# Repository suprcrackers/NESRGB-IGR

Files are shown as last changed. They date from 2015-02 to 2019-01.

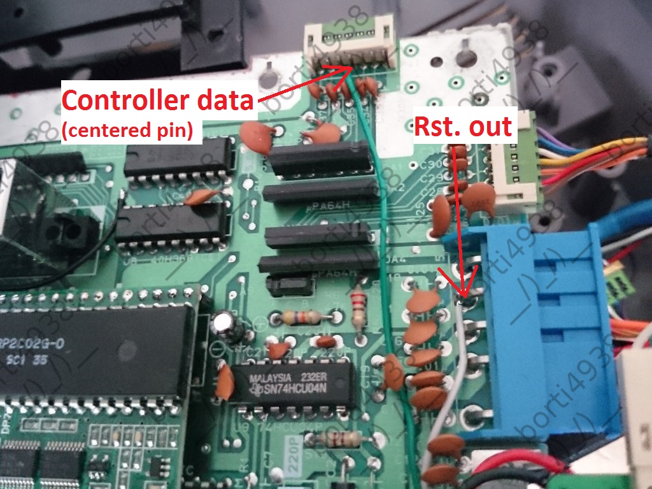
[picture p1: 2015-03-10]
Normal-Version/Installation/Frontloader_ResetOut_Data.jpg

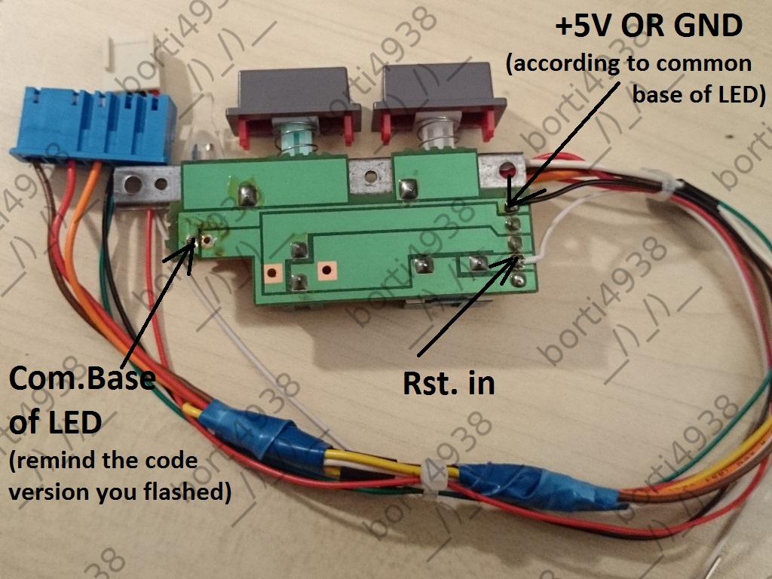
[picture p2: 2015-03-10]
Normal-Version/Installation/Frontloader_Frontpanel_mod.jpg

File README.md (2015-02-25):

# NESRGB-IGR
here you find PCBs and Codes for the NESRGB-IGR :)

If you successfully add the NESRGB-IGR you have the following functionalities available:  

Controller: Start+Select+ ...  
    - ... A+B pressed for <2s: short reset  
    - ... A+B pressed for >2s: long reset (going back to main menu if a power pak is used or in EDN8 reset to game is enabled)  
    - ... D-Pad right: Forward switching through the palette and RGB off (RGB off only available if set by jumper)  
    - ... D-Pad left: Backward switching through palette  
Reset:  
    - short push <~750ms: reset  
    - second punsh while PIC resets the NES/FC: reset as long long as button is held  
    - keeping pressed: forward switching through the palette and RGB off with delay of ~750ms for each palette   

Please note that one is not allowed to connect the PIC directly to the NESRGB.  
If you do so, the CPLD on the NESRGB will be destroyed because the PIC running with NESRGB-IGR-code is designed to run with +5V.  
I recommend to use a 74LVX125 running with 3.3V in between - this IC allows inputs up to +5V.

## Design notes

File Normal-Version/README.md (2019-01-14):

Grab the firmware for the PIC16F684 [here](https://github.com/borti4938/Switchless-Mods/tree/master/NES/IGR_for_NESRGB/)

-  current version: use the 'normal version' and flash the nesrgb_igr_684_var_led.hex
- oldest PCB version (with three 10k resistors next to the 74*125): use the 'risky version' and flash nesrgb_igr_684_risky_var_led.hex

The assembler file include some installation notes which can be used if you want to install the mod into a non-frontloader NES.

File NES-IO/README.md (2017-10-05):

NES-I/O
========

an idea by Arcade-TV from circuit-board.de :) Thank you very much!!!

The board replaces the silver box in NES frontloader. On this PCB the following components are included:

- AC input jack
- AC to DC conversion
- MultiAV (SNES and GC(*) are supported) 
- PIC16F684 microcontroller to control the NESRGB color palette and reset the console using your controller :D

All components you need are stated on the silkscreen. An complete overview as well as an English installation guide is coming soon ;)

Grab the firmware for the PIC16F684 here: https://github.com/borti4938/Switchless-Mods/tree/master/NES/IGR_for_NESRGB/
- current version: use the 'normal version' and flash the nesrgb_igr_684_var_led.hex
- oldest PCB version (with three 10k resistors next to the 74*125): use the 'risky version' and flash nesrgb_igr_684_risky_var_led.hex

(*) 3d-printed Helder/Buffalowing connector on assemblergames (http://assemblergames.com/l/threads/f-s-nes-top-loader-snes-style-multi-a-v-socket.50494/) also fits  
    thanks for figuring out, splits (shmups forum)

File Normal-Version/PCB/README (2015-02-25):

Components:

IC1: PIC16F684 SOIC-14 with NESRGB-IGR code. Please choose whether you want to use a dual LED with a common anode or cathode in advance!
IC2: 74LVX125 SOIC-14

C1, C2: 100nF 0805
R1, R2: 220Ohm 0805

Jumper:

J1: 10kOhm 0805 -> set the reset type of your console there.
J2: Short the jumper you want to... '3' means that the PIC cycles only through the RGB modes; '4' als cycles through RGB off

PCB-order:

Please choose your preferred service.
You may order that PCB at OSHPark -> https://oshpark.com/shared_projects/C9jdssMN

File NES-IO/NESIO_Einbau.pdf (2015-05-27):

# Workflow

### - Jumper festlegen - Alle Litzen und das Video Kabel werden an der Helferplatine

vorbereitet.

### - Das 6-adrige beigelegt Kabel ist für Audio/Video-Leitung, damit auf dem Weg von der NESRGB-PCB zur Helferplatine keine Störungen eingefangen werden! - Die Schirmung des 6-adrigen Kabels geht an Masse - Der 4-Pin-Header mit Buchse und Crimp-Kontakte ist optional!

Litzen können auch direkt auf die Pads gelötet werden.

### (Ich habe die Litzen in die Crimp-Kontakte gelötet und mit ner einfachen Zange zusammengedrückt )

- Der große 5-Pin-Header wird erst auf die Helferplatine gelötet,

### später mit dem NES verbunden. Leider gibt es dort keine Masse. Die

muss leider per Hand gelegt werden.

## Alles im Detail später – auf geht‘s ^^

# Jumper setzen

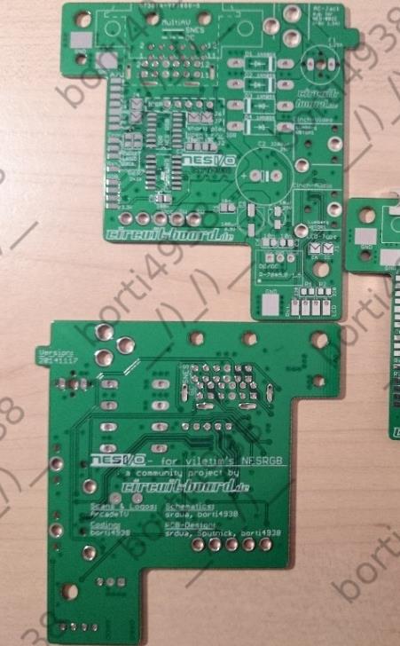
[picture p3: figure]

Es gibt insgesamt 7 Jumper auf der Platine verteilt
- J1: LED-Type: einen der beiden Pads kurzschließen.
CA = gem. Pluspol an LED
CC = gem. Minuspol an LED
- J2: Ist einfach nur n 10k Widerstand (vorgelötet)
- J3: #Modes entfällt in der aktuellen Version – drei Modi ist Fix!!!
- J4: MAV-Pin9. Entscheidet euch, womit gesynct werden soll bei RGB
oben: mit dem Composite Sync bzw. Luma unten: mit Composite Video
- J5: entfällt/nicht vorhanden.
- J6/J7: Die müssen nur aufgemacht werden, wenn man den NESRGB-IGR neu flashen möchte. Im Betrieb gehören die ZU!!!

# Litzen vorbereiten Part 1

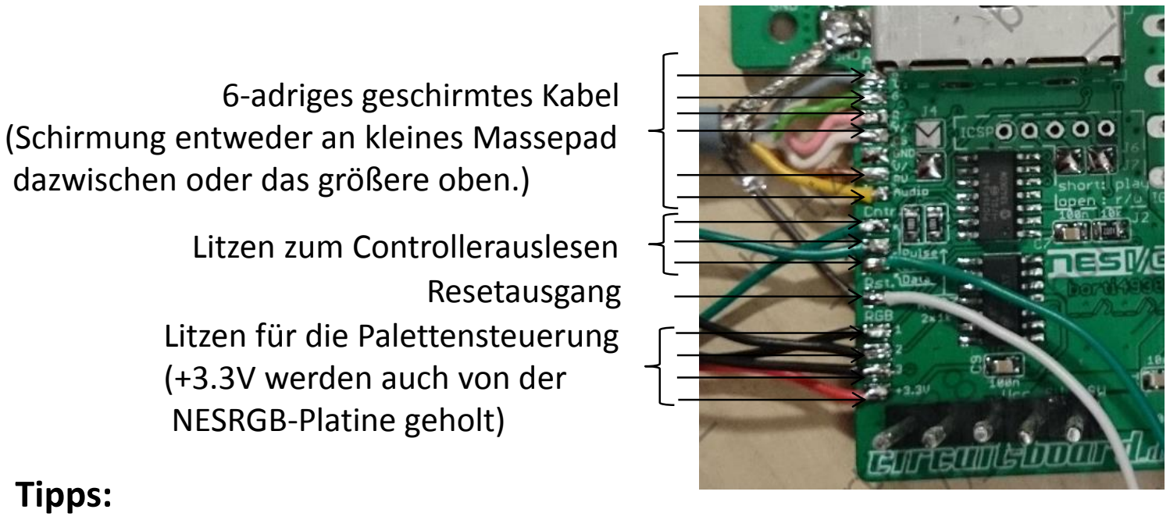
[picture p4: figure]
6-adriges geschirmtes Kabel (Schirmung entweder an kleines Massepad dazwischen oder das größere oben.); Litzen für die Palettensteuerung (+3.3V werden auch von der NESRGB-Platine geholt); Litzen zum Controllerauslesen Resetausgang; Tipps:

- Litze für Resetausgang und Data (Controller) nach rechts wegführen
- Massepads sind für Massekabel und werden später gelötet
(muss nicht vorbereitet werden)

# Litzen vorbereiten Part 2

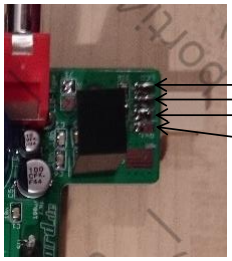
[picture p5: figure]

Tipps:
- GND-Pad wird später genutzt
- Reseteingang und LED-Steuerung kommen vom Frontpanel,
wo LED, Powerknopf und Resetknopf drauf sind. Deswegen empfiehlt sich hier n Pinheader mit Buchse, es sind aber auch einfache Litzen möglich (hier längere Litzen einplanen)
- Wenn Pinheader: BITTE von unten anbringen

LED-Steuerung (von oben nach unten: R, gem. Pol, G) Reseteingang

# NES-Mainboard vorbereiten

- Vor der Vereinigung von Helferplatine und NES-Mainboard,

## noch n Masseleitung anbringen - Masseleitung muss n gute Dicke haben (man kann auch mehrere verlegen; ich habe zwei verlegt)

Ich habe die ‚alten‘ Masselöcher der Box dafür verwendet,

## von unten n Litze anzubringen - Für den Elko muss n kleine Ecke vom Mainboard abgeknipst

oder abgefeilt werden.

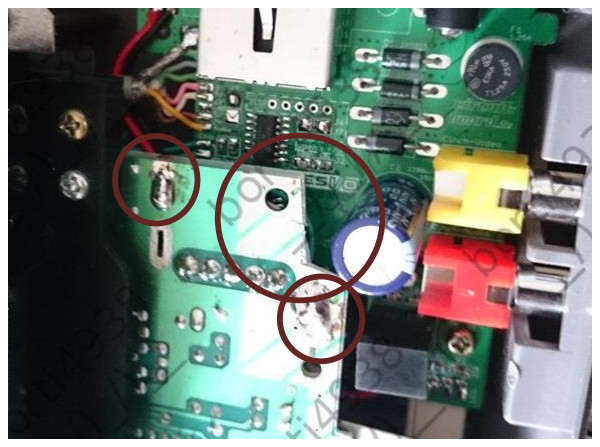
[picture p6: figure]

# Mit NES „vereinen“

### Damit alles gut sitzt, empfiehlt es sich, wie folgt vorzugehen: - 5-Pin-Header auf die Helferplatine löten! - Helferplatine im Gehäuse festschrauben - Untere Schirmung reinlegen, dabei muss ein kleines Ende unter die

Helferplatine geschoben werden.

(Litzen vorsichtig so hinlegen, dass keine im Weg ist) - Mainboard auflegen und auch provisorisch festschrauben (hier nochmal auf die losen Litzen achten) - Schauen, dass alles gut sitzt - 5-Pin-Header anlöten - Masseleitung auf die großen Pads der Helferplatine anlöten - Alles wieder ausschrauben und rausnehmen

### Nun geht’s auf die Zielgeraden

# Audio/Video verlegen

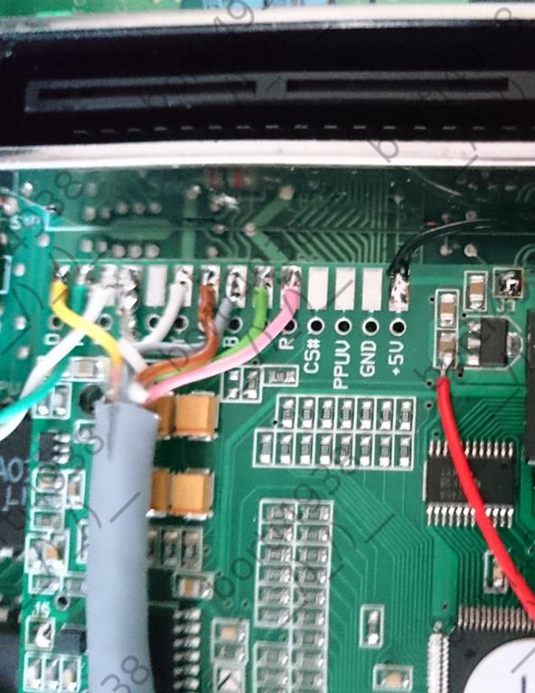
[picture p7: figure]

- Für das Audio/Video-Kabel eine angenehme Länge wählen
- ACHTUNG: Mit der Masseschirmung keinen Kurzschluss auf dem NESRGB-Board verursachen -> ggf. Abisolieren
- Achtet auf die Farben, die ihr an der Helferplatine gewählt habt!
- Audio ist „O“
- Video: entscheidet ob PPUV oder V
- CS: entscheidet, ob /CS oder Y. Dieses Signal liegt später am MultiAV Pin 7 an (für die ‚Luma‘-Syncer)

# Litzen verlegen – Part 1

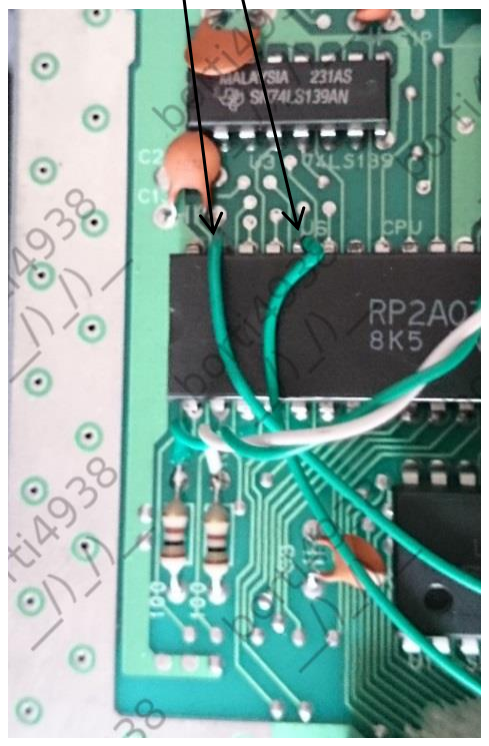
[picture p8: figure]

Controller Latch (U6 CPU Pin39)
Controller Pulse (U6 CPU Pin36)

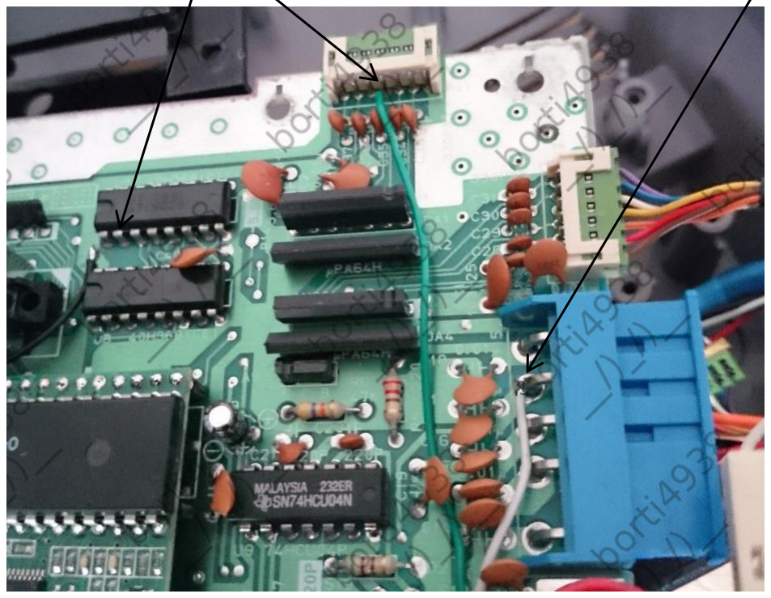
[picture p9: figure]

Controller Data (U7 Pin2) oder am Joypad-Anschluss Pin 4

Resetausgang
(zweiter Pin von unten,
alternativ CIC Pin7)

# Litzen verlegen – Part 2

Palettenswitch
(auf 1, 2 und 3 achten)

+3.3V
(am Kerko mit anlöten)

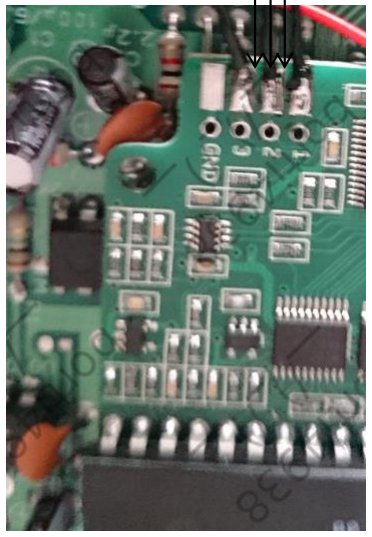
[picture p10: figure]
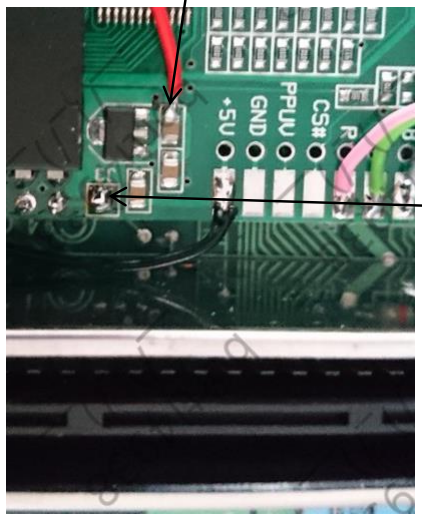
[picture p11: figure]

Hinweis:
Dieser Jumper kann zu und der zum NESRGB-Board beiliegende DC/DC weggelegt werden ;)

# Litzen verlegen – Part 3

Reseteingang
(zweiter von oben)
LED-C
(gemeinsamer Pol)
- Original LED entfernen und eine RG- oder RGB-LED einsetzen
- Gemeinsamer Pol durch die hier rechte Durchkontaktierung

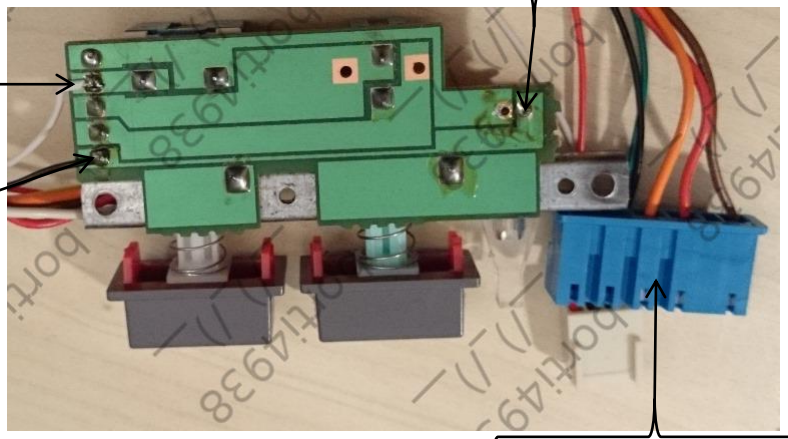
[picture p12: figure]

An diesem Stecker müssen das gelbe und das weiße Kabel (Pin 4 und 5) entfernt werden
(abknipsen oder den Stift rausdrücken)

# FERTIG

# Viel Spaß !!!

# PS: beim Zusammenbauen darauf achten, dass keine Litze gequetscht wird. Aber eigentlich sollte alles passen

# Fragen und Hinweise bitte an borti4938@gmx.de

# Funktionsweise NESRGB-IGR

- Controller: Start+Select+ ...
- ... A+B gedrückt unter 2s: Kurzer Reset
- ... A+B gedrückt für über 2s: Langer Reset
(zurück ins Hauptmenü beim Power Pak)
- ... D-Pad rechts:
Vorwärts durch die Paletten und durch RGB off schalten
(Delay je 750ms; RGB off nur bei entsprechend gesetztem Jumper)
- ... D-Pad left: Rückwärts durch die Paletten schalten
- Resetknopf:
- kurzes Drücken unter 750ms: Reset
- Beim Reset erneut drücken und gedrückt halten:
Reset wird solange durchgeführt, wie der Knopf gehalten wird
- Langes Drücken mind. Über 750ms:
Vorwärts durch die Paletten und durch RGB off schalten
(Delay je 750ms; RGB off nur bei entsprechend gesetztem Jumper)

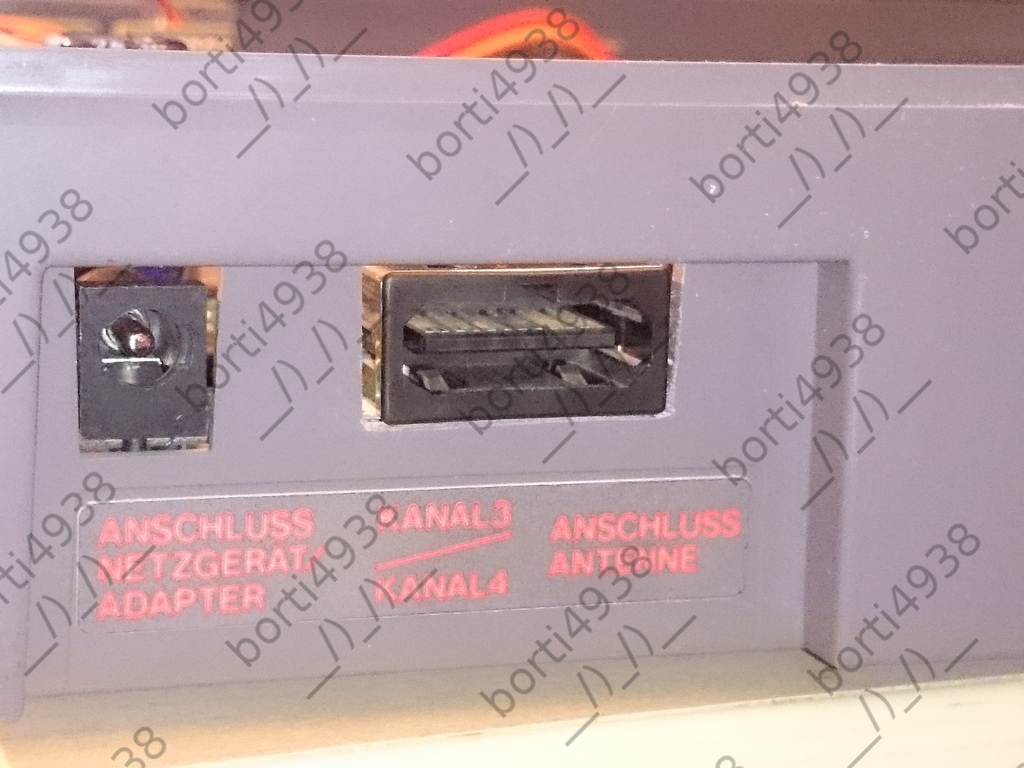
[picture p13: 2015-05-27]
NES-IO/pictures/GC-Buchse.jpg

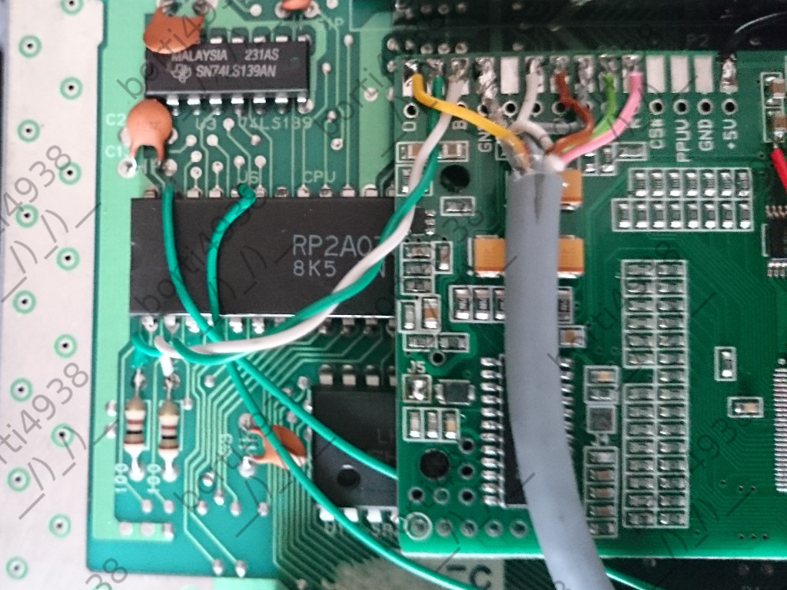
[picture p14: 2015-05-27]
NES-IO/pictures/Clk_Pulse.jpg

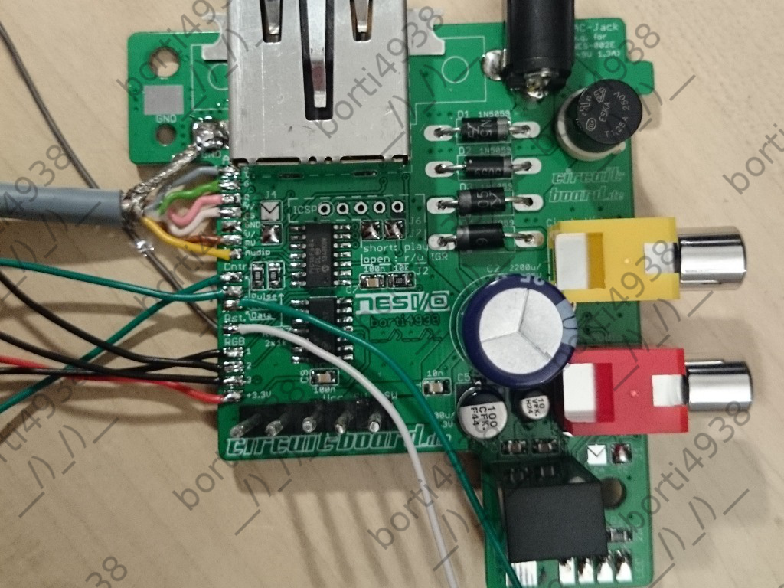
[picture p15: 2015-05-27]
NES-IO/pictures/Litzenvorbereitung.jpg

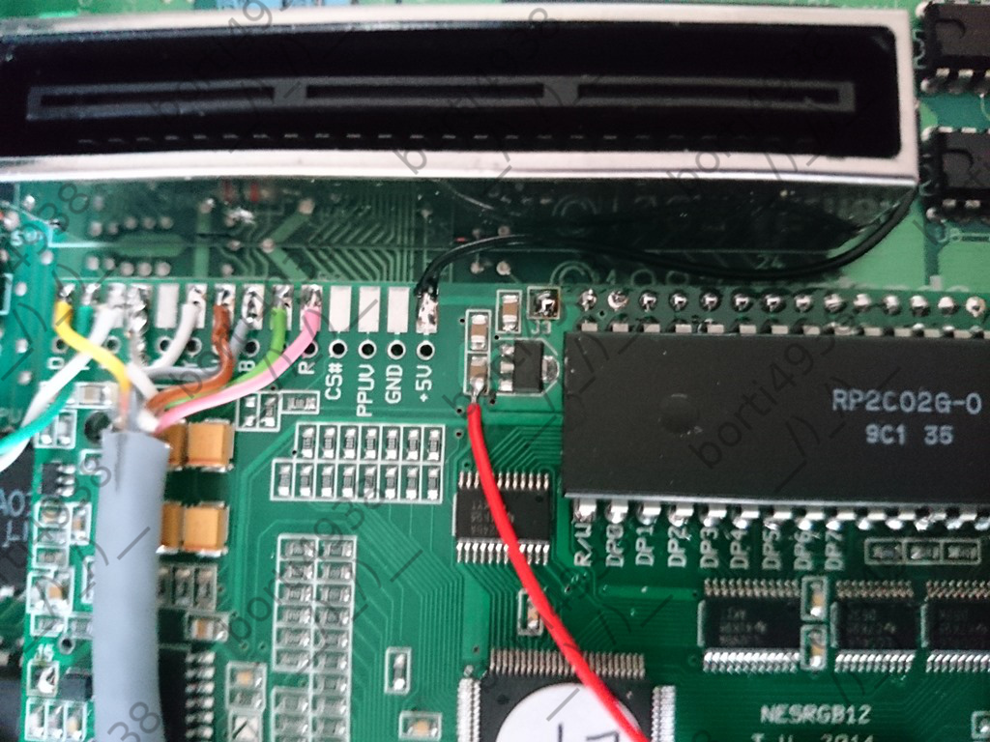
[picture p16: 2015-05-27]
NES-IO/pictures/NESRGB.jpg

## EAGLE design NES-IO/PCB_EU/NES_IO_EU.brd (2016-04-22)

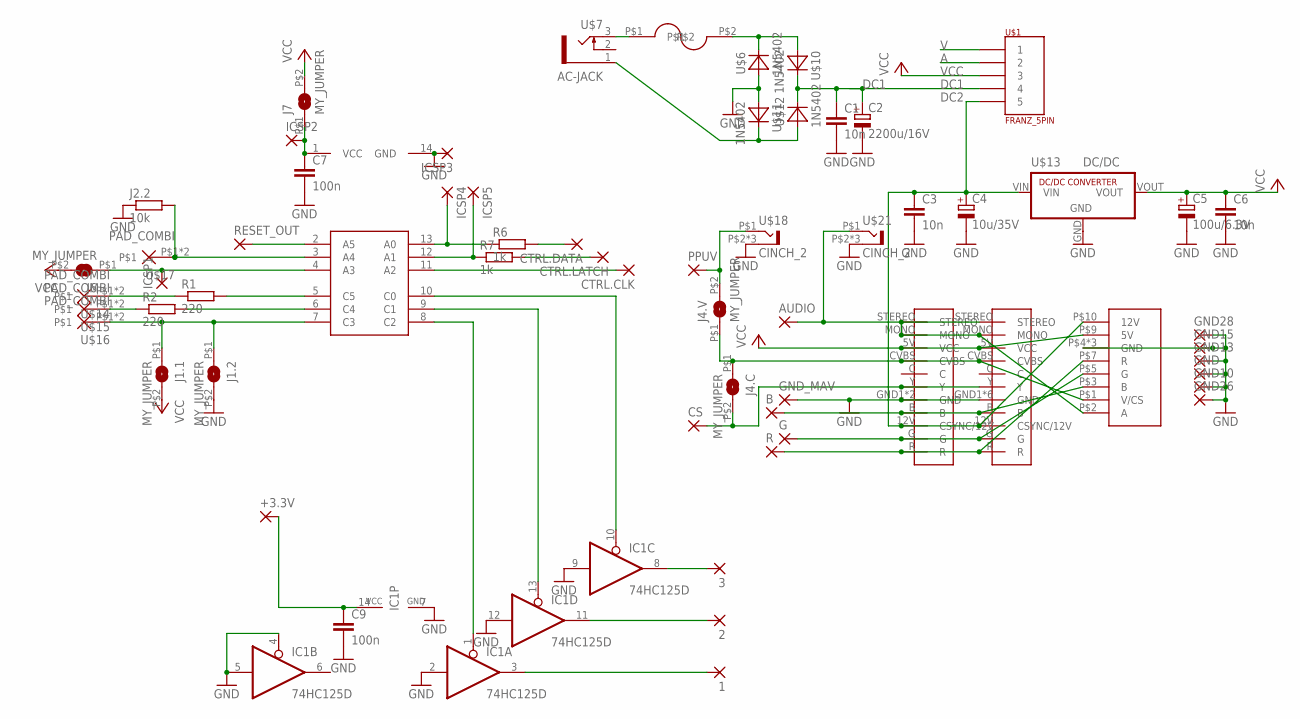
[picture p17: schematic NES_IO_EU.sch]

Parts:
1, 2, 3: SMD2; SMD1,27-2,54
+3.3V: SMD2; SMD1,27-2,54
AUDIO: SMD2; SMD1,27-2,54
B: SMD2; SMD1,27-2,54
C1, C3, C6: 10n; Z0805
C2: 2200u/16V; E5-13
C4: 10u/35V; PANASONIC_B
C5: 100u/6.3V; PANASONIC_D
C7, C9: 100n; Z0805
CS: SMD2; SMD1,27-2,54
CTRL.CLK, CTRL.DATA, CTRL.LATCH: SMD2; SMD1,27-2,54
G: SMD2; SMD1,27-2,54
GND, GND10, GND13, GND15, GND26, GND28: SMD5; SMD2,54-5,08
GND_MAV: SMD2; SMD1,27-2,54
IC1: 74HC125D; SO14
ICSP1, ICSP2, ICSP3, ICSP4, ICSP5: 1,6/0,8
J1.1, J1.2, J4.C, J4.V, J6, J7: MY_JUMPER; MYJUMP
J2.2: 10k; Z0805
PPUV: SMD2; SMD1,27-2,54
R: SMD2; SMD1,27-2,54
R1, R2: 220; Z0805
R6, R7: 1k; Z0805
RESET_OUT: SMD2; SMD1,27-2,54
U$1: FRANZ_5PIN; 5X2.22RM4
U$2: FUSEHOLDER
U$5: PIC16F630_SIMPLE; PIC16F630
U$6, U$10, U$11, U$12: 1N5402; DO201
U$7: AC-JACK
U$8: NESFR_JACK2
U$13: DC/DC; RECOM
U$14, U$15, U$16, U$17: PAD_COMBI
U$18, U$21: CINCH_2
U$19: GC-MULTIAV
U$20: SNES-MULTIAV2

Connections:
A: U$1.P$2 (2)
AC1A: U$2.P$1, U$7.3
AC1B: U$2.P$2, U$6.C, U$10.A
AC2: U$7.1 (5), U$11.C, U$12.A
DC1: C1.1, C2.+, U$1.P$4 (4), U$10.C, U$12.C
DC2: C3.1, C4.+, U$1.P$5 (5), U$8.P$10 (12V), U$13.VIN, U$19.12V (CSYNC/12V), U$20.12V (CSYNC/12V)
GND: C1.2, C2.-, C3.2, C4.-, C5.-, C6.2, C7.2, C9.2, GND.1, GND10.1, GND13.1, GND15.1, GND26.1, GND28.1, GND_MAV.1, IC1.2 (I), IC1.4 (OE), IC1.5 (I), IC1.7 (GND), IC1.9 (I), IC1.12 (I), ICSP3.1, J1.2.P$2 (2), J2.2.1, U$5.14 (GND), U$6.A, U$8.P$4 (GND), U$8.P$6 (GND), U$8.P$8 (GND), U$11.A, U$13.GND, U$18.P$2 (S), U$18.P$3 (S), U$18.P$4 (S), U$19.GND1 (GND), U$19.GND2 (GND), U$19.GND3 (GND), U$19.GND4 (GND), U$19.GND5 (GND), U$19.GND6 (GND), U$20.GND1 (GND), U$20.GND2 (GND), U$21.P$2 (S), U$21.P$3 (S), U$21.P$4 (S)
unnamed: AUDIO.1, U$8.P$2 (A), U$19.MONO, U$19.STEREO, U$20.MONO, U$20.STEREO, U$21.P$1 (T)
unnamed: B.1, U$8.P$3 (B), U$19.B, U$20.B
unnamed: CS.1, J4.C.P$2 (2), U$19.Y, U$20.Y
unnamed: G.1, U$8.P$5 (G), U$19.G, U$20.G
unnamed: R.1, U$8.P$7 (R), U$19.R, U$20.R
unnamed: 3.1, IC1.8 (O)
unnamed: J2.2.2, U$5.3 (A4), U$17.P$1, U$17.P$2
unnamed: R1.2, U$5.5 (C5)
unnamed: R2.2, U$5.6 (C4)
unnamed: R1.1, U$14.P$1, U$14.P$2
unnamed: R2.1, U$15.P$1, U$15.P$2
unnamed: J1.1.P$1 (1), J1.2.P$1 (1), U$5.7 (C3), U$16.P$1, U$16.P$2
unnamed: CTRL.DATA.1, R6.2
unnamed: CTRL.LATCH.1, R7.2
unnamed: CTRL.CLK.1, U$5.11 (A2)
unnamed: IC1.10 (OE), U$5.10 (C0)
unnamed: IC1.13 (OE), U$5.9 (C1)
unnamed: IC1.1 (OE), U$5.8 (C2)
unnamed: +3.3V.1, C9.1, IC1.14 (VCC)
unnamed: 1.1, IC1.3 (O)
unnamed: 2.1, IC1.11 (O)
unnamed: J4.V.P$2 (2), PPUV.1, U$18.P$1 (T)
unnamed: J4.C.P$1 (1), J4.V.P$1 (1), U$8.P$1 (V/CS), U$19.CVBS, U$20.CVBS
unnamed: C7.1, ICSP2.1, J7.P$1 (1), U$5.1 (VCC)
unnamed: ICSP1.1, J6.P$1 (1), U$5.4 (A3)
unnamed: ICSP4.1, R6.1, U$5.13 (A0)
unnamed: ICSP5.1, R7.1, U$5.12 (A1)
unnamed: RESET_OUT.1, U$5.2 (A5)
V: U$1.P$1 (1)
VCC: C5.+, C6.1, J1.1.P$2 (2), J6.P$2 (2), J7.P$2 (2), U$1.P$3 (3), U$8.P$9 (5V), U$13.VOUT, U$19.5V (VCC), U$20.5V (VCC)

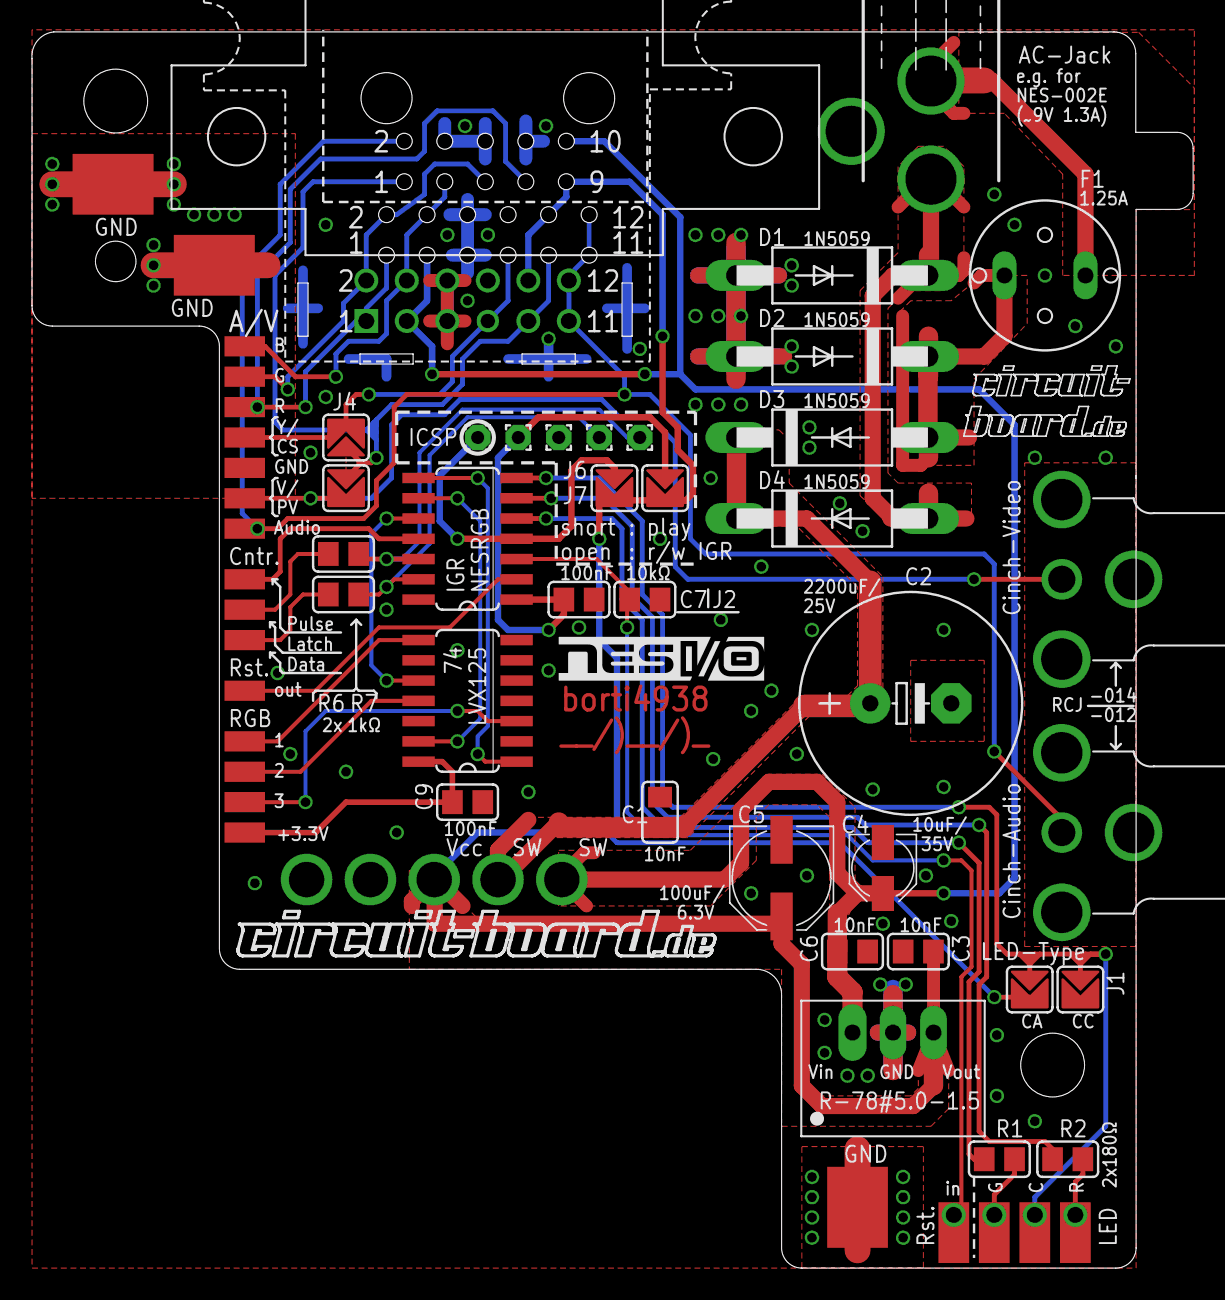
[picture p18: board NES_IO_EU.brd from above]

Board: 2 copper layers, 72.8 x 77.5 mm, 66 parts (1 on the bottom side), 35 nets.

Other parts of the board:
U$3, U$4: NESIO-LOGO

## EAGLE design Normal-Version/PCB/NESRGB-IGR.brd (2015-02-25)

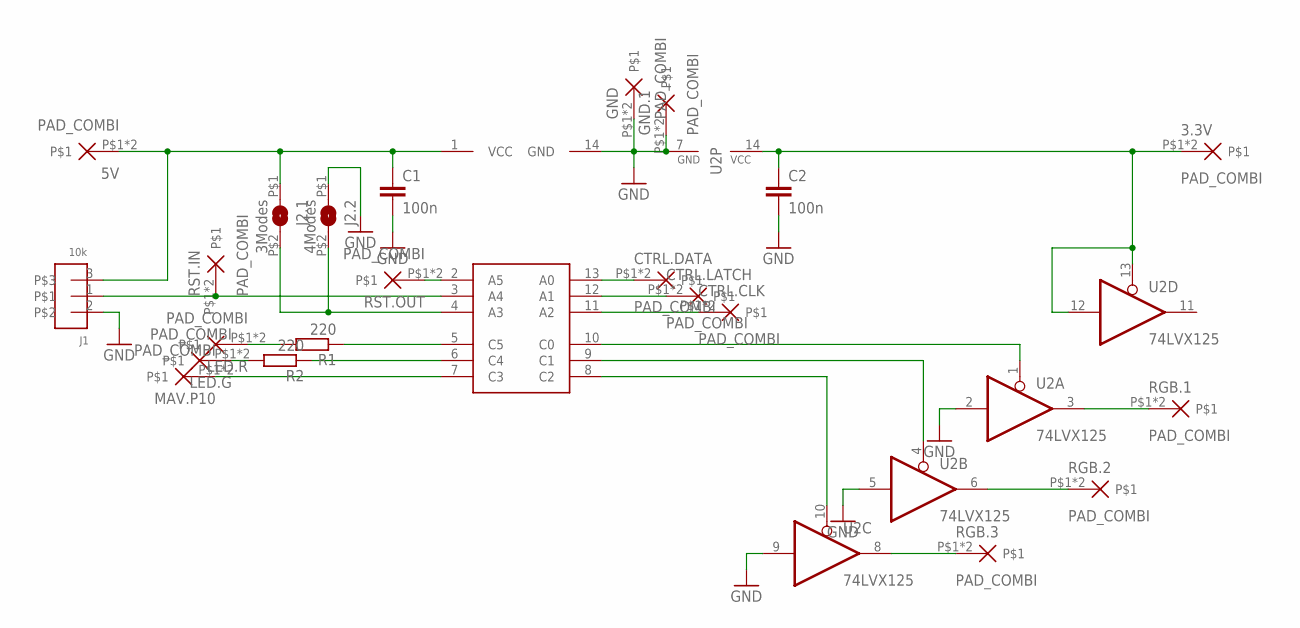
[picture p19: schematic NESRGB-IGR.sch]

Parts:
3.3V, 5V: PAD_COMBI
C1, C2: 100n; Z0805
CTRL.CLK, CTRL.DATA, CTRL.LATCH: PAD_COMBI
GND, GND.1: PAD_COMBI
J1: 10k; Z0805-JUMPER
J2.1: 3Modes; MYJUMP
J2.2: 4Modes; MYJUMP
LED.G, LED.R: PAD_COMBI
MAV.P10: PAD_COMBI
R1, R2: 220; Z0805
RGB.1, RGB.2, RGB.3: PAD_COMBI
RST.IN, RST.OUT: PAD_COMBI
U1: PIC16F684; PIC16F630
U2: 74LVX125; SO14

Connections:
GND: C1.2, C2.2, GND.P$1, GND.P$2, GND.1.P$1, GND.1.P$2, J1.2, J2.2.P$1 (1), U1.14 (GND), U2.2 (I), U2.5 (I), U2.7 (GND), U2.9 (I)
unnamed: J1.1, RST.IN.P$1, RST.IN.P$2, U1.3 (A4)
unnamed: 5V.P$1, 5V.P$2, C1.1, J1.3, J2.1.P$1 (1), U1.1 (VCC)
unnamed: R2.1, U1.6 (C4)
unnamed: J2.1.P$2 (2), J2.2.P$2 (2), U1.4 (A3)
unnamed: MAV.P10.P$1, MAV.P10.P$2, U1.7 (C3)
unnamed: 3.3V.P$1, 3.3V.P$2, C2.1, U2.12 (I), U2.13 (OE), U2.14 (VCC)
unnamed: CTRL.DATA.P$1, CTRL.DATA.P$2, U1.13 (A0)
unnamed: CTRL.LATCH.P$1, CTRL.LATCH.P$2, U1.12 (A1)
unnamed: CTRL.CLK.P$1, CTRL.CLK.P$2, U1.11 (A2)
unnamed: LED.G.P$1, LED.G.P$2, R2.2
unnamed: LED.R.P$1, LED.R.P$2, R1.2
unnamed: RST.OUT.P$1, RST.OUT.P$2, U1.2 (A5)
unnamed: U1.10 (C0), U2.1 (OE)
unnamed: U1.9 (C1), U2.4 (OE)
unnamed: U1.8 (C2), U2.10 (OE)
unnamed: R1.1, U1.5 (C5)
unnamed: RGB.3.P$1, RGB.3.P$2, U2.8 (O)
unnamed: RGB.2.P$1, RGB.2.P$2, U2.6 (O)
unnamed: RGB.1.P$1, RGB.1.P$2, U2.3 (O)

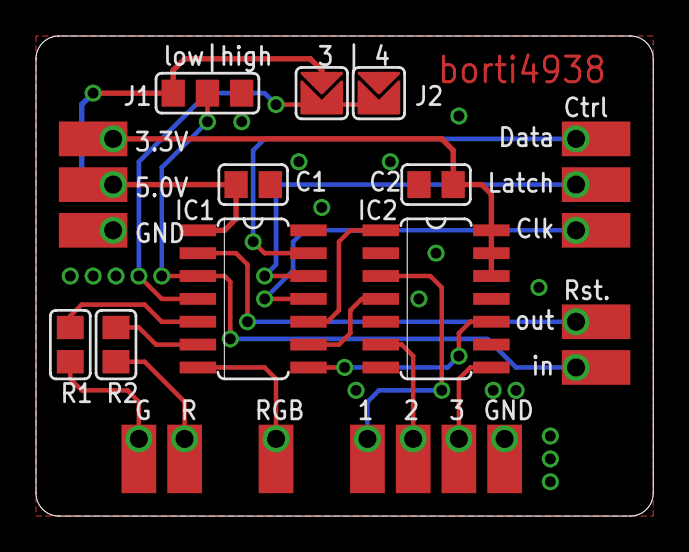
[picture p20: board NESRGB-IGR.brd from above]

Board: 2 copper layers, 34.3 x 26.7 mm, 24 parts (0 on the bottom side), 20 nets.

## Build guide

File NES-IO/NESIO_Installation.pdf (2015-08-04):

# Workflow

## - Set Jumpers

- Prepare the NES-I/O with all cables.

## - Use a 6-pole grounded-shield cable is for audio/video signals to reduce noise influence from NESRGB to NES-

I/O

## - Use a four pin header and jack to have a flexible connection between front panel and NES-I/O (I soldered cables to the pins of the jack as I do not have a crimp tool) - Reuse the big 5-pole header out of the silver box you

replace with the NES-I/O. Desolder it.

# Details in the following ;) Let‘s go!

# Set jumpers


Es gibt insgesamt 7 Jumper auf der Platine verteilt
- J1 (two jumpers): LED-Type: short just one, never close both!
CA = LED with common anode
CC = LED with common cathode
- J2: just a 10k resistor
- J3: discontinued!!!
- J4 (two jumpers): sync on pin 9 MultiAV. Short at …
… top: Raw Sync or Luma Sync
… bottom: composite video
- J5: discontinued.
- J6/J7: close both for normal operation. Just open them if you want to reprogram the PIC16F684

# Prepare cables - Part 1

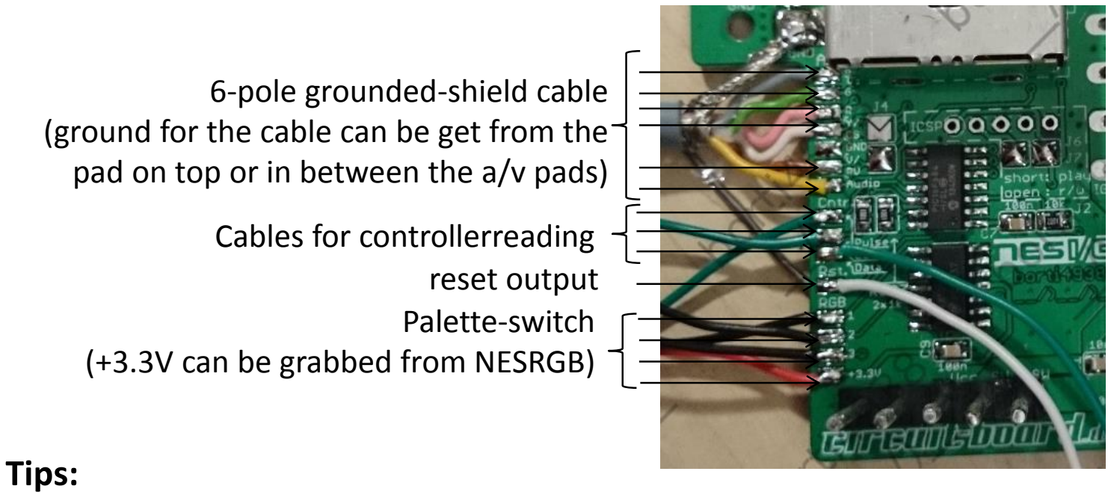
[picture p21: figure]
6-pole grounded-shield cable; pad on top or in between the a/v pads); Palette-switch (+3.3V can be grabbed from NESRGB); Cables for controllerreading reset output; Tips:

(ground for the cable can be get from the

- Place cables for reset output and controller data to the rigth
- Large pads for ground has to be used later

# Prepare cables - Part 2


Tipps:
- Large pads for ground has to be used later
- Reset and led comes from front panel, where
LED, power button and reset button are. Use a flexible connection here and long cables here
- If you use a pinheader: solder it to the bottom side of the NES-I/O

LED-control (from top to down): R, comon pole, G) Reset input

# NES-Mainboard preparation

## - Desolder the silver box and remove the large 5-pole header - Prepare cables for ground connection between NES-I/O and NES - Use multiple cables with a quite large diameter Personally I used the old - Remove a small piece from the NES mainboard such that the new elko can fit


# Connect NES-I/O with the NES

### I suggest doin‘ the following steps: - Solder the 5-pole header to the NES-I/O! - Fix the NES-I/O into the housing with two screws - Place NES mainboard together with the lower radiation shield into

the housing.

### (make sure that non of the prepared cables is clamped) - Fix everything with some screws - If everything fits quite well, solder the big 5-pole header - Solder the prepared cables for ground connection to the NES-I/O - Remove everything from the housing again

### Only a few steps are left

# Audio/Video wiring


- Cut your 6-pole grounded-shield cable into a good length
- BE CARFEFUL: do not produce a short with the shield
- Connect each pole the the NESRGB according to the connection with the NES-I/O!
- „O“ is audio
- video: use either PPUV or V
- /CSYNC: use either CS# or Y.
This signal is later connected to MultiAV pin 7 anyway (in case you use a RGB cable with ‚Luma‘-sync)

# General connections – Part 1


Controller Latch (U6 CPU pin39)
Controller Pulse (U6 CPU pin36)

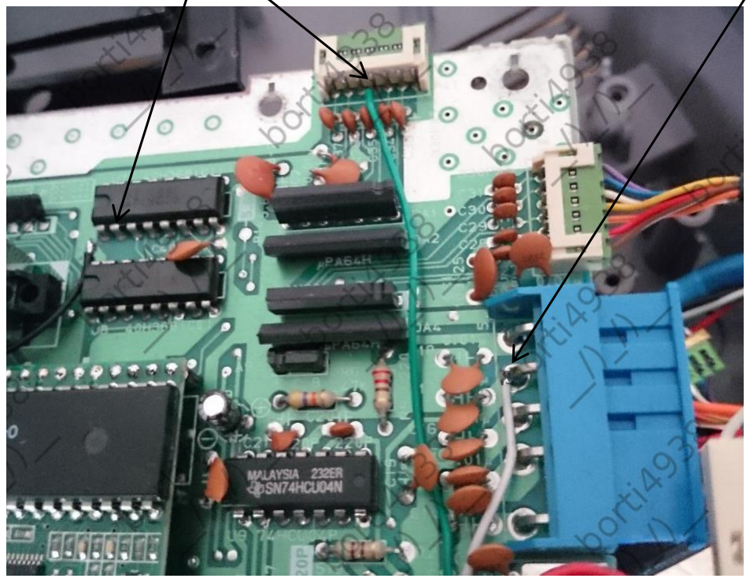
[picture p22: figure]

Controller Data (U7 pin2) or am Joypad-jack pin 4

Reset output
(secound pin from top,
or CIC pin7 alternatively)

# General connections – Part 2

Palette switch
(1, 2 und 3)

+3.3V
(solder to the ceramic capacitor)


Small hint:
Close the Jumper
The DC/DC comming with the NESRGB is not needed ;)
You may use a second wire on +5V to have a better connection with Vcc

# General connections – Part 3

Reset input
(second point from top)
LED-C
(common pole of LED)
- Remove original LED and place
a RG- oder RGB-LED here
- Use the right via for the common pole

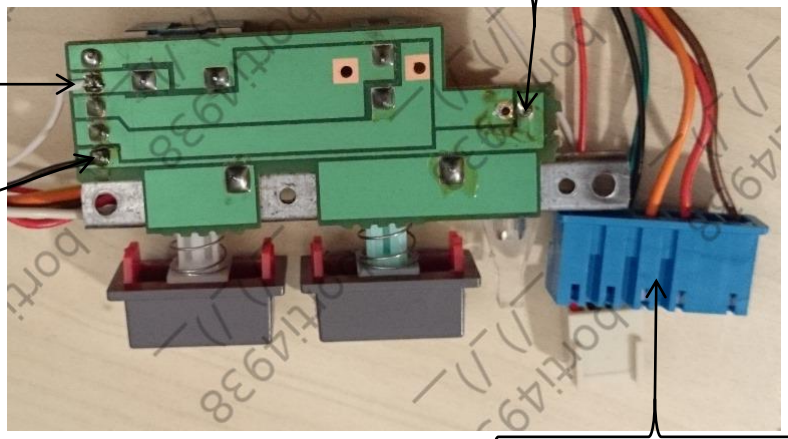
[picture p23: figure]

Remove the white an yellow cable from this big blue connector (pin 4 and 5) (cut or remove)

# THAT‘S IT

# Have fun!!!

# PS: please make sure that none of your cables is clamped while putting everything together

# Questions or Hints? Contact me… borti4938@gmx.de https://github.com/borti4938

# In-Game-Routines of the NES-I/O

- Controller: Start+Select+ ...
- ... A+B pressed for less than 2s: Short Reset
- ... A+B pressed longer than 2s: Long Reset
(Go back to main menu of flashcards)
- ... D-Pad right:
switch through the palettes (with a delay of 750ms) (natural -> improved -> garish -> natural -> …)
- ... D-Pad left: switch through palettes backward
- Reset button:
- short button push (less than 750ms): reset
- push again and keep pressing while console is resetted: reset impulse continues as long as you hold the button down
- hold button (at least for 750ms):
switch through the palettes

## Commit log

2015-02-25 initial commit PCB
    [NESRGB-IGR.brd]
2015-05-27 [WIP] NES-I/O design with the RGB-output jack of the France version of the NES
    [NES_IO_FR.brd, NES_IO_FR.sch]
2015-05-27 Add eagle design NES-I/O
    [NES_IO.brd, NES_IO.sch]
2015-06-15 revert a small meaningless error (by an coding error RGB was switched off everytime a reset was requested by controller for a short moment)
2015-09-28 new controller reading strategy; back to the roots - change controller button bit on falling edge (interrupt steered) - sample bit ~1.5us after rising edge
2015-10-08 Huge code clean up with minor improvements: - clean up code - set interrupt flags on demand - start controller reading using global interrupt - revert small mistake introduced with last commit at pre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
2015-12-20 Common design for MultiAV (from SNES or GC) and FR-NES-RGB jack
    [NES_IO.brd, NES_IO.sch, NES_IO_FR.brd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]
2015-12-20 Gerber Files for NES-I/O (EU)
2015-12-28 Update PCB and its name (EU version)
    [NES_IO_EU.brd, NES_IO_EU.sch]
2015-12-28 Add US version of the NES-I/O difference to the NES-I/O (EU) is only the pinout of the MultiAV (see info file)
    [NES_IO_US.brd, NES_IO_US.sch]
2015-12-28 update Gerber files
2015-12-28 add gerber files for the US version of the NES-I/O
2015-12-28 update Gerber files using appropriate excellon for EAGLE 7.5
2016-02-27 enable weak pull-up at reset line to console if low-active is detected Some CPUs (especially those in Twin Famicoms) seems to not have an internal weak pull-up (WPU). Without the PICs WPU, one has to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
2016-04-22 Update PCB files
    [NES_IO_EU.brd, NES_IO_EU.sch, NES_IO_US.brd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]
